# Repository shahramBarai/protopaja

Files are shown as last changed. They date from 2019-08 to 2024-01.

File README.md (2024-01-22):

# Etäohjattava virranohjausmoduuli (Protopaja 2019)

**Tämä projekti on osa Aalto-yliopiston [Protopaja](https://protopaja.aalto.fi/) kurssia (kesäkuusta elokuuhun 2019).*

## 1. Johdanto
Yhtiö tarvitsee älykkään järjestelmän ohjaamaan eri sähkölaitteita. Ideana on rakentaa laite, joka
tulisi kiinni pistorasiasta lähtevään johtoon tai mahdollisesti voitaisiin jo suunnitteluvaiheessa
integroida sähkölaiteen rungon sisälle. Laitteella pystyy käynnistämään ja sulkemaan siihen
linkitetyt sähkölaitteet. Tämän lisäksi laite mittaa sähkönkulutusta. Ohjaamiseen yhtiö on
ehdottanut Blynk nimistä ohjelmistoa, jolla etäohjaus tapahtuu wifi:n, bluetoothin tai esim. suoraan
USB:n kautta. 

## 2. Tavoite
Järjestelmän avulla pystyy tarkkailemaan siihen linkitetyn sähkölaitteen energiankulutusta, ja
ohjaamaan laitteen käynnistämistä tai sulkemista etänä tämän datan pohjalta järjestelmään kuuluvan
sovelluksen avulla.
Järjestelmä on ensisijaisesti suunnattu kotitalouksille, ja näin ollen sen loppukäyttäjiä ovat
kuluttajat. Demonstraatiossa otamme sovelluksesta WiFin kautta yhteyden pistorasiaan
asennettavaan laitteeseen, ja käynnistämme ja sammutamme järjestelmän kautta lampun. 

## 3. Tulokset 
Lopputuloksena meillä on tomiva virranmittauspiiri, joka lähettää Blynk-sovellukselle
reaaliaikaisesti dataa sähkönkulutuksesta. Lisäksi Blynk-sovelluksella voidaan laittaa sähkövirta
laitteeseen päälle ja pois. 

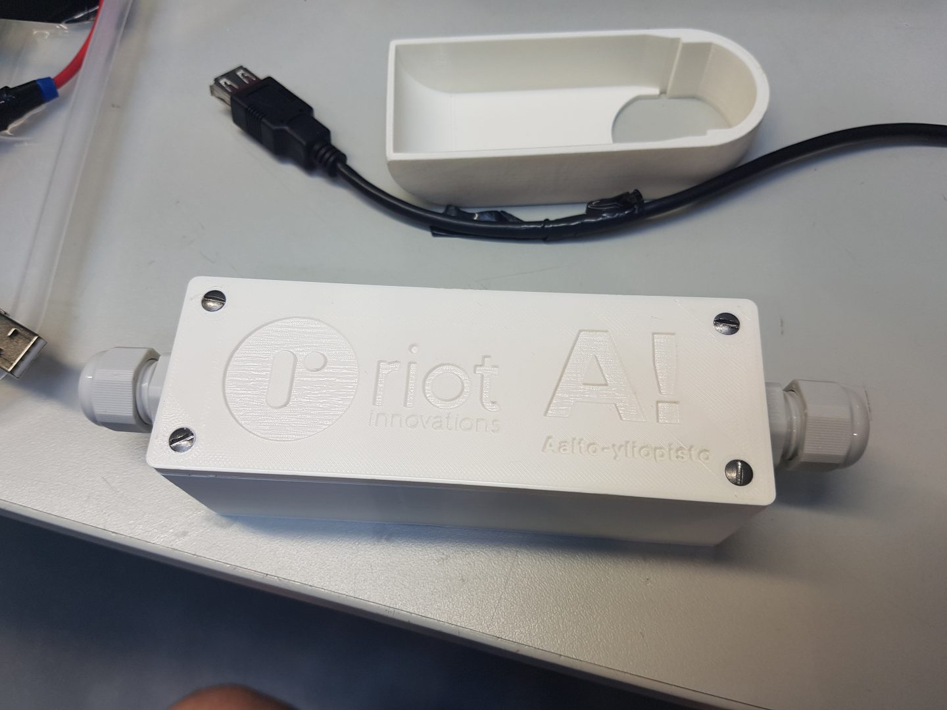
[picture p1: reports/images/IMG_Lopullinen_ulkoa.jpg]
Lopullinen_ulkoa

Kuva 1: Virranmittauspiiri ulkoa.

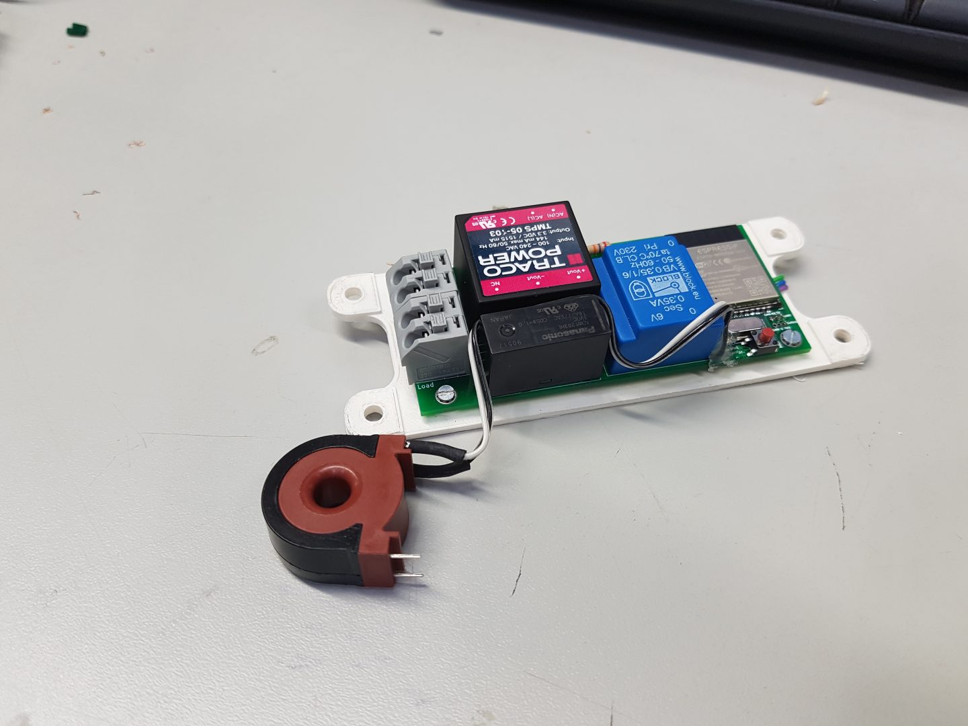
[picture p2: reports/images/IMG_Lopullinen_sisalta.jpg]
Lopullinen_sisalta

Kuva 2: Virranmittauspiiri sisältä. 

### 3.1 Tekninen toiminta
Moduulissa on energianmittauspiiri CS-5490, mikä mittaa virran ja jännitteen, ja lähettää siitä tiedon ESP32-mikrokontrollerille. Blynk-sovellus lähettää mikrokontrollerille tiedon sähkön hinnasta. ESP32 laskee energian kulutuksen, tehon ja sähkölaskun suuruuden ja välittää informaation Blynk-sovellukselle.

Käyttäjä näkee Blynk-sovelluksesta kätevästi tilanteen. Lisäksi käyttäjä voi käskeä katkaisemaan sähkövirran sovelluksesta. Sovellus lähettää tällöin tiedon ESP32:lle, mikä katkaisee virran kulun piirin lävitse. Käyttäjä voi myös avata virran uudelleen sovelluksen kautta.

Blynk ja ESP32 kommunkoivat WiFi:n välityksellä. Sähkövirtaa ohjataan releellä.

### 3.2 Blynk-mobiilisovellusalusta
Blynk on mobiilisovellusalusta joka auttaa kommunikoimaan IoT-laitteiden kanssa (Internet of Things, esineiden internet). Se on yhteensopiva hyvin moneen mikrokontrolleriin ja se tarjoaa kehittämistä varten kattavan kirjaston. Käytimme Blynkkiä virranohjausmoduulin ohjaussovelluksen tekemiseen.

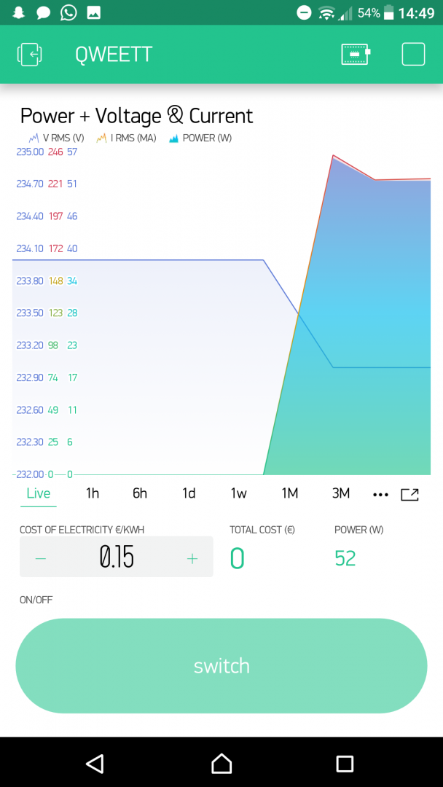
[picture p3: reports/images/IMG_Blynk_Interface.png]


Kuva 3: Kuvakaapaus Blynk-mobiilisovelluksen käyttäjän rajapinnasta. Sovellus sekä näyttää energiankulutuksen, että siitä voi laittaa laitteen sähkövirran päälle tai pois.

## 4. Piirin suunnittelu

**Lisätietoja elektroniikkapiiristä löytyy täältä [KiCad/..](./KiCad/)**

## 5. Ohjelmointi

**Lisätietoja ESP32 lähtökoodistä löytyy täältä [src/..](./src/)**

## 6. Fyysinen kotelo

**Lisätietoa fyysisestä kotelosta löytyy täältä [Autodesk Fusion 360/..](./Autodesk%20Fusion%20360/)**

## Linsensi
Tämä teos on lisensoitu Creative Commons Nimeä 4.0 Kansainvälinen -lisenssillä. Tarkastele lisenssiä osoitteessa http://creativecommons.org/licenses/by/4.0/ tai lähetä kirje osoitteeseen Creative Commons, PO Box 1866, Mountain View, CA 94042, USA.

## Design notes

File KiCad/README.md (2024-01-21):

## Piirin suunnittelu

### Sähkökytkentäkaavio

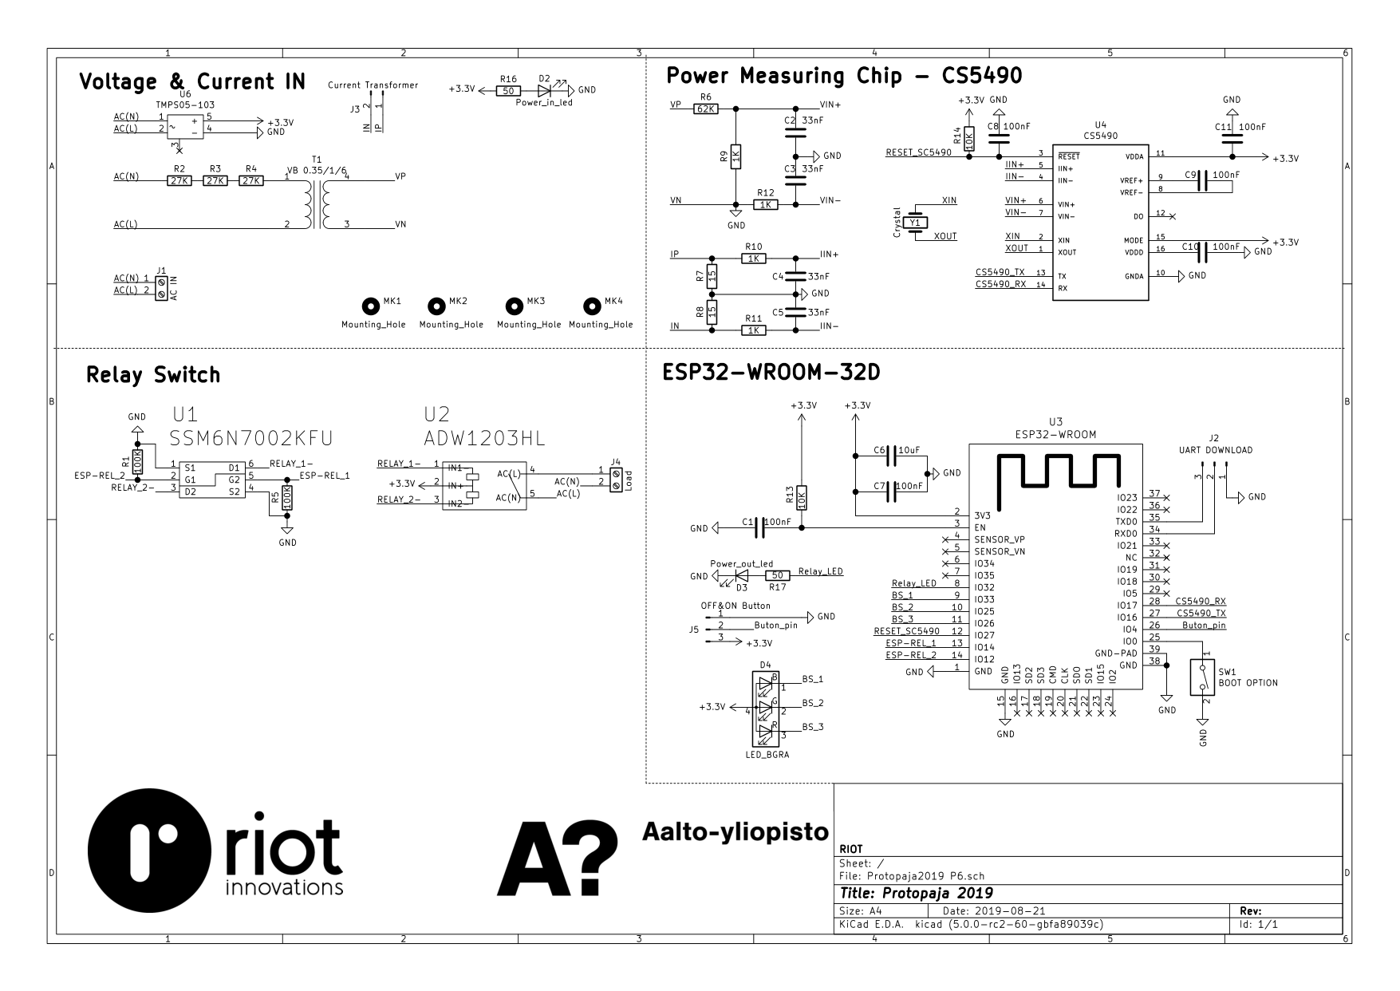
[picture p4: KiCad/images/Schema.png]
Schema


### PCB layouts
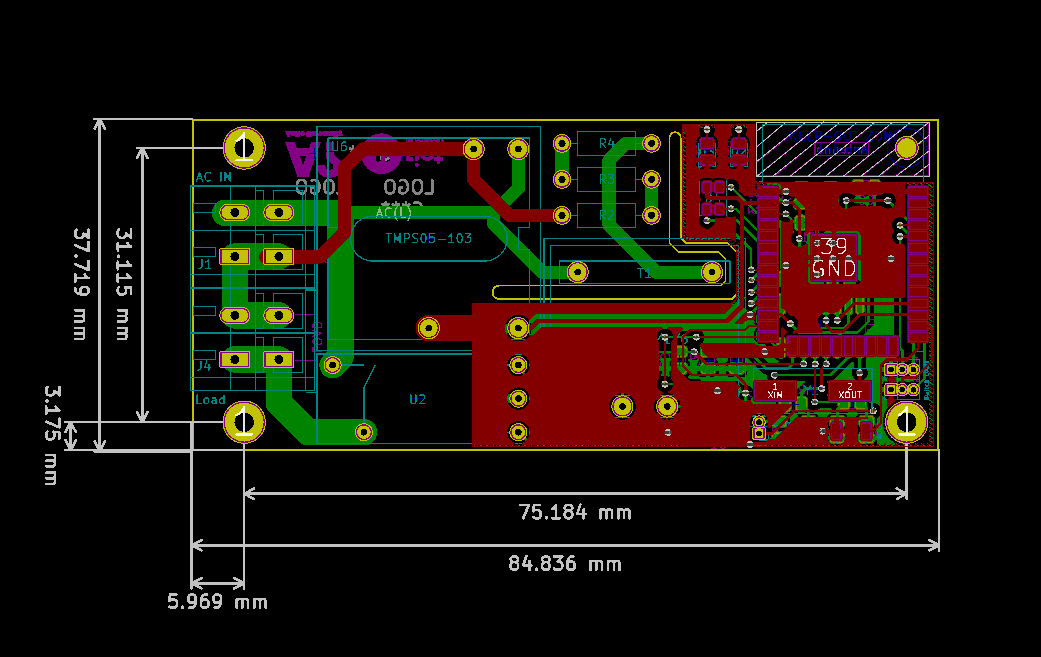
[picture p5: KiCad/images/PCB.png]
PCB


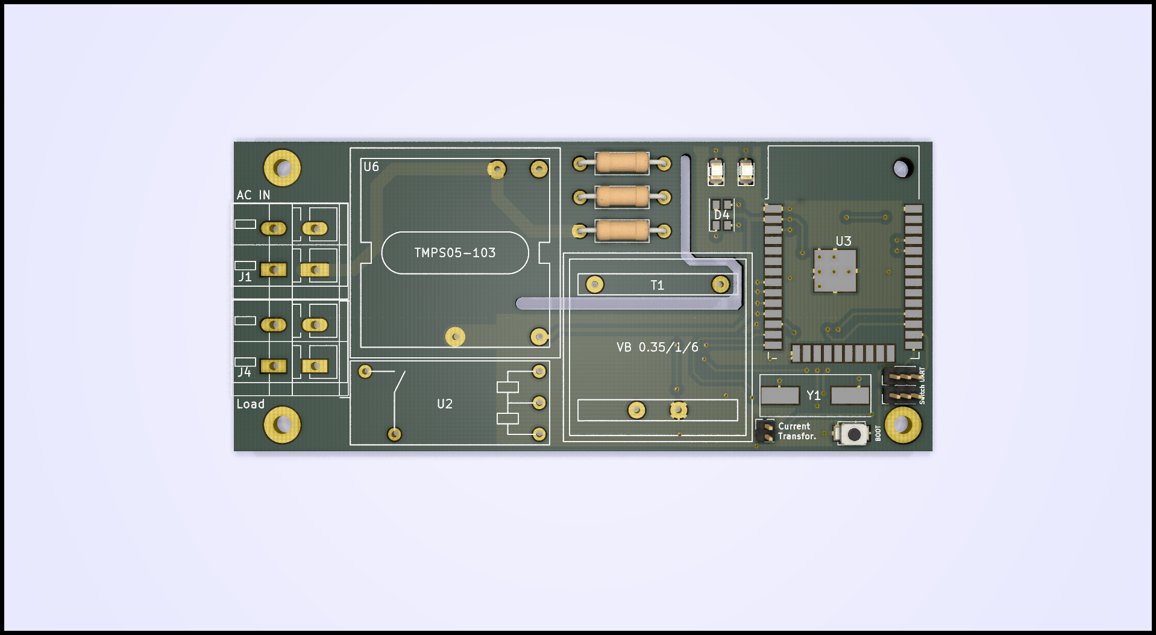
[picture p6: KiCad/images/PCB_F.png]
PCB_F


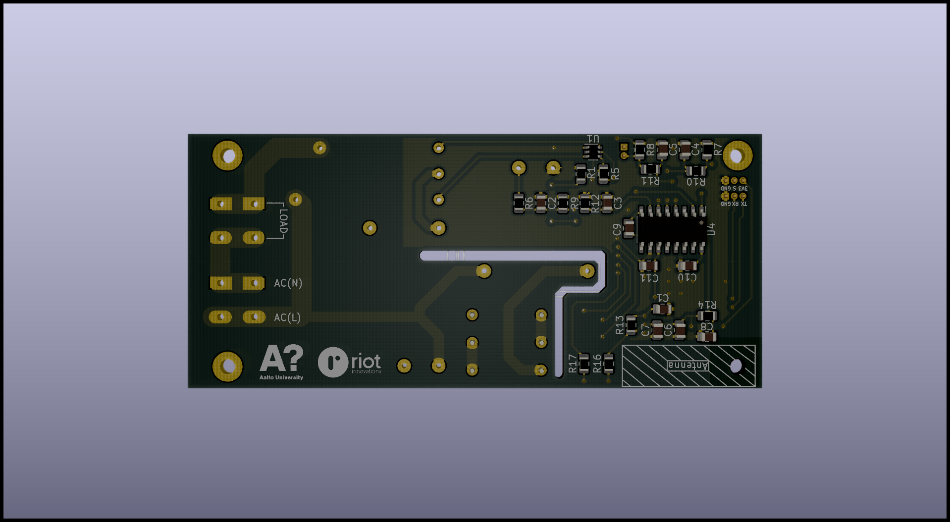
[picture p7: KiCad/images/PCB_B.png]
PCB_B


### Komponenttilista

| Item | Part | Component | Qty | Cost/unit | Pricing (1000pcs) |
| --- | --- | --- | --- | --- | --- |
| 1 | MCU WLAN | ESP32-WROOM-32D | 1 | 3,42 | 3,42 |
| 2 | Energy measuring circuit | CS-5490 | 1 | 3,35 | 1,67 |
| 3 | Current Transformer | T60404-E4622-X501 | 1 | 10,93 | 5,01 |
| 4 | Relay | ADW1203HLW | 1 | 5,24 | 3,07 |
| 5 | AC/DC power | TMPS 05-103 | 1 | 16,38 | 12,94 |
| 6 | Isolated Transformer | VB 0.35/1/6 | 1 | 5,98 | 4,33 |
| 7 | Chrystal | ABLS2-4.096MHZ-D4Y-T | 1 | 0,50 | 0,19 |
| 8 | LED Green | KPT-2012LCGCK | 1 | 0,0161 | 0,0565 |
| 9 | LED Red | KPT-2012SRC-PRV | 1 | 0,0308 | 0,0612 |
| 10 | Wire-To-Board Terminal Block| 	235-402/331-000 | 2 | 0,036 | 0,30 |
| 11 | or | 250-502 | 2 | 0,037 | 0,332 |
| Total |  |  |  | **45,82** | **31,23** |

** Resistors, capacitors and leds are used 0805 case. You can find components here: 
[KiCad/Components_list.png](./images/Components_list.png)

## Linsensi
Tämä teos on lisensoitu Creative Commons Nimeä 4.0 Kansainvälinen -lisenssillä. Tarkastele lisenssiä osoitteessa http://creativecommons.org/licenses/by/4.0/ tai lähetä kirje osoitteeseen Creative Commons, PO Box 1866, Mountain View, CA 94042, USA.

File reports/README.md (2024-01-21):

**Since the reports contain personal information about other team members and curator, it was decided not to make the files __"Projectisuunnitelma.pdf"__ and __"Loppuraporti.pdf"__ publicly available.*

***If you would like to access them, please contact the person who provided you with the link to this repository.*

## Linsensi
Tämä teos on lisensoitu Creative Commons Nimeä 4.0 Kansainvälinen -lisenssillä. Tarkastele lisenssiä osoitteessa http://creativecommons.org/licenses/by/4.0/ tai lähetä kirje osoitteeseen Creative Commons, PO Box 1866, Mountain View, CA 94042, USA.

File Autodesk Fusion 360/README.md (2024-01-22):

### Fyysinen kotelo

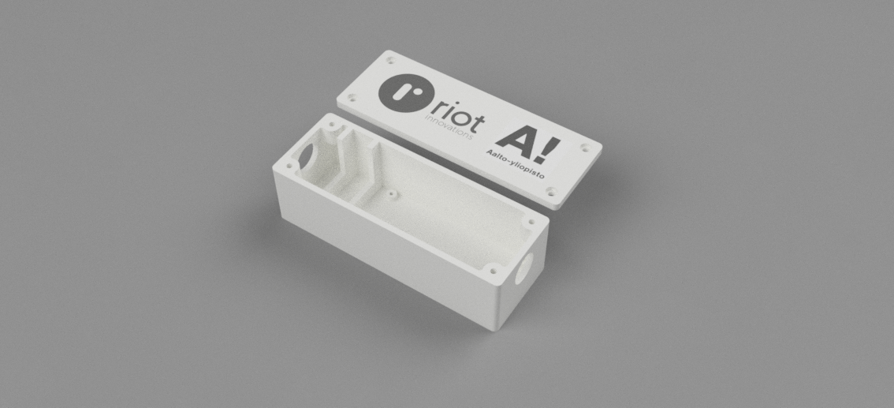
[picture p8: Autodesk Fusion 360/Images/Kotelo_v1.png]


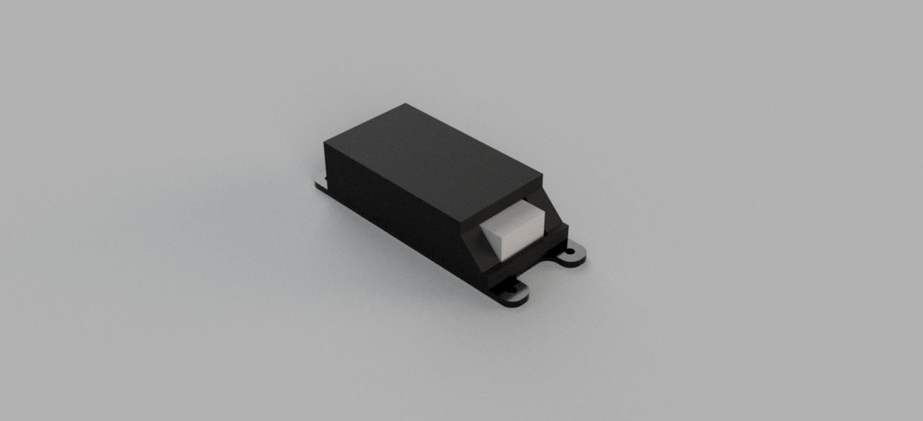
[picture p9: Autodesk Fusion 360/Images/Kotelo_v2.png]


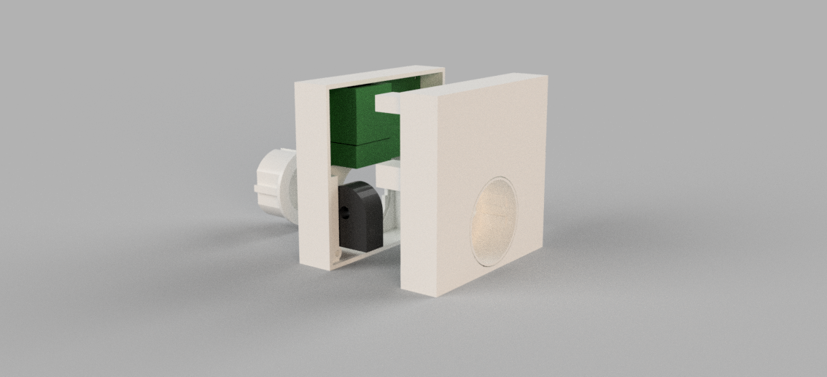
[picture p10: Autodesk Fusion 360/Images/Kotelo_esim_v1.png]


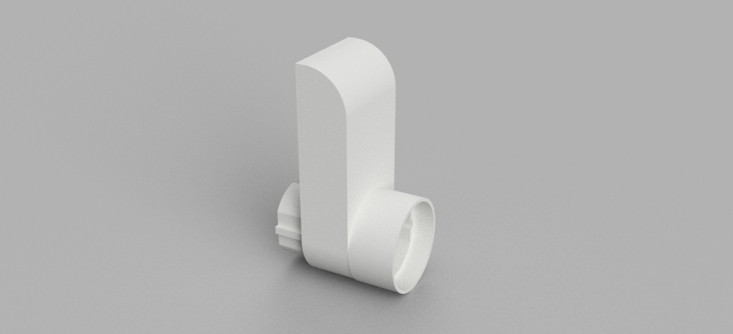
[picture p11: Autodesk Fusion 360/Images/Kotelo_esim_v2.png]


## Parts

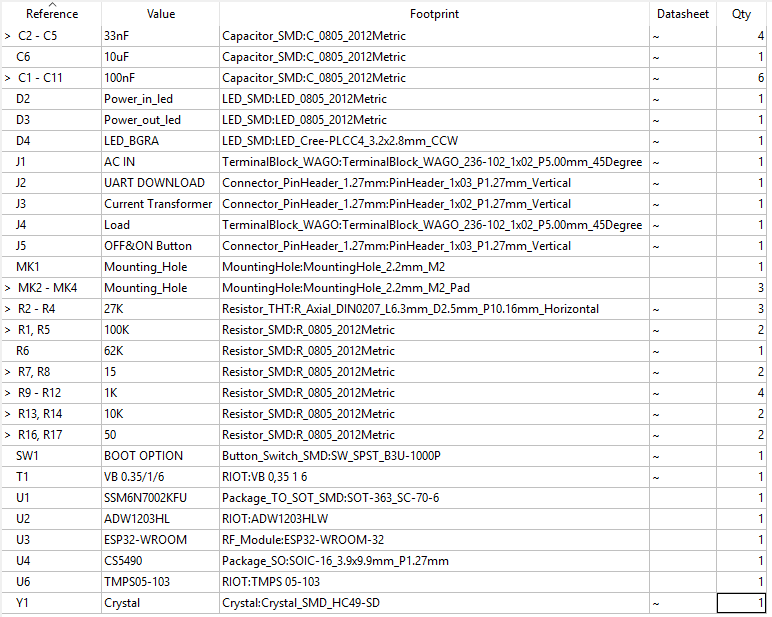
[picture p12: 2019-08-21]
KiCad/images/Components_list.png

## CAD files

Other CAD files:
Autodesk Fusion 360/Kotelo_esim_v1.f3d
Autodesk Fusion 360/Kotelo_esim_v2.f3d
Autodesk Fusion 360/Kotelo_v1.f3d
Autodesk Fusion 360/Kotelo_v2.f3d

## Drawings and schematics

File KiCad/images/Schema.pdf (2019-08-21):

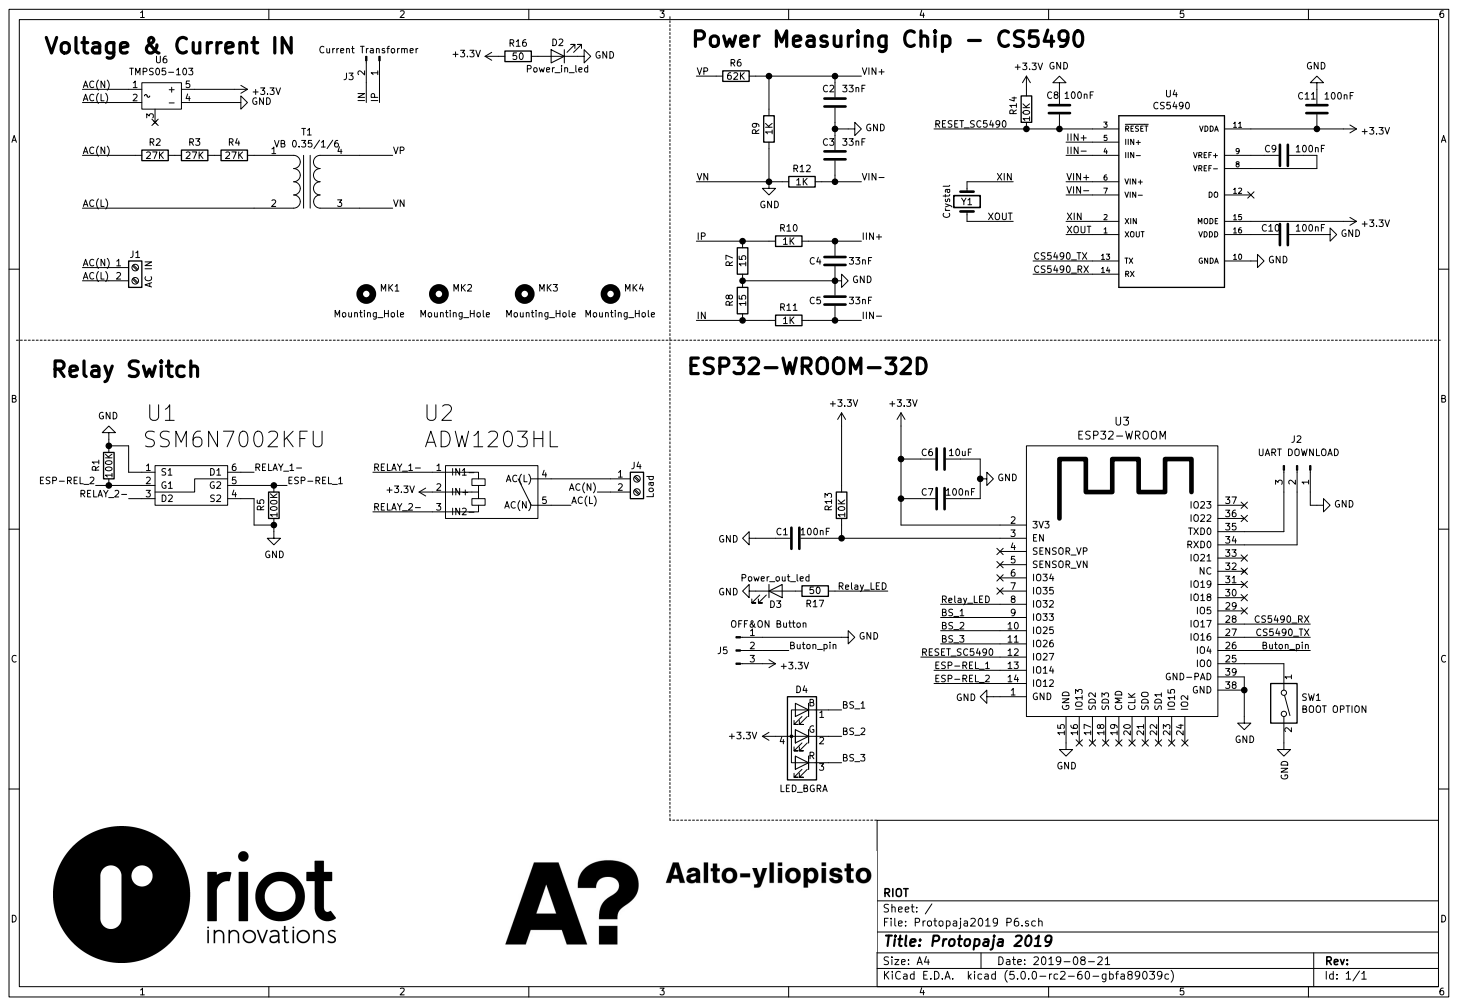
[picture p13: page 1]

VN Voltage & Current IN

IN Power Measuring Chip - CS5490

File: Protopaja2019 P6.sch Sheet: / RIOT

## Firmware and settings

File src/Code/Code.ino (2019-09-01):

/*********************************************************************************************************************************************
  Aalto protopaja summer 2019 in collaboration with Riot innovations.
  
  Code runs with an esp-32 - wifi module using "Blynk" as an user interaction app, which uses its own cloud. 
  (Note that all functions which use blynk are marked so that in future it would be easier to be able to possibly change to another framework.)
  
  Before installing code remember to switch devise to boot mode by pressing boot-button for 10 seconds while plugging the device into socket.
  For operation remember to restart device by turning it off and on after loading new code.

  Copyright (c) . All rights reserved. Licensed under the MIT License.
**********************************************************************************************************************************************/

#define REELAY_OFF 14
#define REELAY_ON 12

#define REELAY_LED 32

#define RGB_R 26
#define RGB_G 25
#define RGB_B 33

#define BUTTON 4 //for on-device -button implementations. Check isButtonPressed() -function, (used in loop)

#define RST_SC5490 27 

//**********-FOR BLYNK-********************
#define BLYNK_PRINT Serial
#include <WiFi.h>
#include <WiFiClient.h>
#include <BlynkSimpleEsp32.h>
char auth[] = "YOUR AUTH. TOKEN";
char ssid[] = "YOUR WIFI";
char pass[] = "YOUR PASSWORD";
//**********-FOR BLYNK END-****************

float readPushValues();

unsigned long time_now = 0;
int readPushDuration = 10000; // = 10 sec, time gap between reading values from an energy meter chip.
const int readPushesQuantSet = 10;
int readPushesQuant = 10;

float energyCost = 0; //In euros
float totalEnergyCost = 0; //In euros

bool reelayOnOff = false;

bool buttonStateOld = false;
bool buttonSwitched = false;
bool BlynkButtonSwitched = false;
bool BlynkButtonStateOld = false;
bool RelayState = false;

void setup(){
  //Serial.begin(115200); //Uncomment theese for serialport communication with computers serial monitor.
  // wait for serial port to connect.
  //while (!Serial);

  // set the data rate for the HardwareSerial 2 port
  Serial2.begin(600);

  pinMode(REELAY_OFF, OUTPUT);
  pinMode(REELAY_ON, OUTPUT);
  pinMode(REELAY_LED, OUTPUT);

  //Restarting chip
  pinMode(RST_SC5490, OUTPUT);
  delay(2000);
  digitalWrite(RST_SC5490, LOW);
  delay(2000);
  digitalWrite(RST_SC5490, HIGH);

  //waking up the chip
  delay(2000);
  Serial2.write(0b11000011);

  //continuousConv.
  delay(2000);
  Serial2.write(0b11010101);

  //**********-FOR BLYNK-********************
  Blynk.begin(auth, ssid, pass);
  //**********-FOR BLYNK END-****************
}

void loop(){
  //**********-FOR BLYNK-********************
  Blynk.run();
  //**********-FOR BLYNK END-****************

  if((millis() > time_now + readPushDuration) || (0 < readPushesQuant)){ //every rad & push duration push the quantity of readPushesQuant
    if (millis() > time_now + readPushDuration){
      readPushesQuant = readPushesQuantSet;
    }
    time_now = millis();
  
  //Calculate next power interval
  //w*€/kwh*second
  totalEnergyCost += ((float)readPushValues() * (float)energyCost/3600000.0 * (((float)millis()-(float)time_now)/1000.0) );
  readPushesQuant--;
  }

  //isButtonPressed(); //Uncomment, if you plan to use on-device button.
  buttonSwitched = relaySwitch(buttonSwitched);
}

int readRmsV(){
  uint32_t value = readReg(16, 7);
  value = -74.1555 + 2 + value*4.053207*(pow(10,-5)); //Calibration function.
 
  if (value < 100 or value > 260){ //Out of realistic range (E.g. the case if no voltage is coming out of the soccet)
    value = 0;
  }
    
  delay(1000);

  return value;
 }

 int readRmsI(){
  uint32_t value = readReg(16, 6);
  value = 0.00000101078*1000*value + 0.00037*1000; //Calibrationfunc. Note the value is returned in milliAmps!
  
  if (value < 40){ //zero all values below 40 milliamps (out of range)
   value = 0;
  }
    
  delay(1000);

  return value;
 }

 float readPF(){
  uint32_t value = readReg(16, 21);

  float val = 0.5228584 - 7.845135E-8 * value + 1.291986E-14*(pow(value,(2)));
  //This function is decent but still because of lack of data at value range 4*10^6 -> 0.98*10^7 it gets unsure values. Also note that under EU legislation no electrical devices can have a powerFactor under 0,95, therefore this calibration function should be very accurate in normal device usage.
  
  if (val > 1){ //No power factor can be greater than 1.
    val = 1;
  }
    
  if (val < 0.4){ //Unrealistic PF.
   val = 0.4;
  }

  delay(1000);

  return val;
 }
 
 float calcP(int V, int I, float PF){
  float P = V * I/(1000) * PF; //Where PF is cos(phase-displacement)
  return P;
 }

//********-instrumentary functions-**********
uint32_t readReg(int page, int adr){
  byte data[3]; //data buffer

  clearSerial2Buffer();

  Serial2.write(0b10000000 + page); //0b10000000 is added because of that how adress writing logic works. Read more in datasheet.
  Serial2.write(adr);

  //wait for 3 bytes to come 
  while(Serial2.available() < 3);

  //read 3 byte info
  for(int i=0; i<3; i++){
    data[i] = Serial2.read();
  }

  //combining data
  uint32_t value = 0;
  value = value + data[2] << 8;
  value = value + data[1] << 8;
  value = value + data[0];
  return value;
}

void clearSerial2Buffer(){ //Clears Serial2 buffer every time before writing to Serial2
  while(Serial2.available()){
    Serial2.read();
  }
}

bool relaySwitch(bool switched){
  if(switched){ 
    RelayState = !(RelayState);

    if (RelayState){
      digitalWrite(REELAY_ON, HIGH);

      delay(1000); 

      digitalWrite(REELAY_ON, LOW);
      digitalWrite(REELAY_LED, HIGH);

      switched = !(switched);

      return switched;
    }
    
    else{
      digitalWrite(REELAY_OFF, HIGH);

      delay(1000);

      digitalWrite(REELAY_OFF, LOW);
      digitalWrite(REELAY_LED, LOW);

      switched = !(switched);

      return switched;
    }
  }
}

void isButtonPressed(){
  bool buttonState = (bool)(digitalRead(BUTTON));

  if (buttonState != buttonStateOld){
    buttonStateOld = buttonState;
    buttonSwitched = true;
  }
}

//**********-BLYNK FUNCTIONS->************
//Blynk virtual pins usage:
//V1 => Energy cost from Blynk
//V6 => Total Energy spent from Blynk
//V5 => Voltage
//V4 => Current 
//V3 => Power

void pushValueC(int val){
  Blynk.virtualWrite(V6, val);
}

BLYNK_WRITE(V1){
  energyCost = (float)(param.asFloat());
}

BLYNK_WRITE(V0){ 
  bool BlynkButtonState = (bool)(param.asInt());

  if (BlynkButtonState != BlynkButtonStateOld){
    BlynkButtonStateOld = BlynkButtonState;
    buttonSwitched = true;
  }
}

void pushValueV(int val){
  Blynk.virtualWrite(V5, val); //Vrites in "V5", a cloud's VirtualPin Register 
}

void pushValueI(int val){
  Blynk.virtualWrite(V4, val); 
}

void pushValueP(float val){
  Blynk.virtualWrite(V3, val);
}

float readPushValues(){
  int valV = readRmsV();
  
  int valI = readRmsI();
  
  float valPF = readPF();

  float valP = calcP(valV, valI, valPF);
  
  //**********-FOR BLYNK-********************
  pushValueV(valV); 
  pushValueI(valI/1000);
  pushValueP(valP);
  pushValueC(totalEnergyCost);
  //**********-FOR BLYNK END-****************

  return valP;
}

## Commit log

2019-08-11 Add KiCad file
2019-08-13 Added a construction that alternates the time while which system reads and pushes values of power analysis
2019-08-13 Added control over relay switch and led indicator
2019-08-13 Added button control for relay
2019-08-13 Now both physical and virtual buton only switch the state at which the relay was. The problem with two buttons stating different boolean values is now solved. Relay's state is indicated by it's led a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
    [Code.ino]
2019-08-14 Code tested (not relay part). Bugs removed.
    [Code.ino]
2019-08-15 Found a PROBLEM in relay control. Reimplemented some constructions of it. Should work now. untested.
    [Code.ino]
2019-08-19 Debugged combined tested.
    blynk led on V2 doesn't work!
2019-08-21 Upload KiCad Files
2019-08-21 Upload PCB.png
2019-08-21 Upload PCB_F.png
2019-08-21 Upload PCB_B.png
2019-08-29 Upload Kanssi_v1 (Kalle)
    [Kanssi_v1.f3d]
2019-08-29 Upload Kanssi_v2 (Shahram)
    [Kanssi_v2.f3d]
2019-08-29 Upload Kanssi_esim_v1 (Shahram)
    [Kanssi_esim_v1.f3d]
2019-08-29 Upload Kanssi_esim_v2 (Aleksi)
    [Kanssi_esim_v2.f3d]
2019-08-29 Upload New File
    [Kotelo_v1.f3d]
